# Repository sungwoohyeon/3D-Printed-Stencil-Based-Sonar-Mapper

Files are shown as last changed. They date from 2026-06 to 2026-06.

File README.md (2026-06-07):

# 3D-Printed Stencil-Based Sonar Mapper

> An **independent, in-progress reproduction** of the core idea behind **SPiDR** —
> generating a 2D cross-sectional depth map from a *single* 40 kHz speaker + a *single*
> microphone + a passive 3D-printed acoustic "stencil", by solving the linear inverse
> problem `y = H·x`.
>
> 단일 40 kHz 스피커 1개 + 마이크 1개 + 3D프린팅 패시브 "스텐실"로 2D 단면 깊이맵을
> 만드는 SPiDR 논문의 **독립 재현 프로젝트**(진행 중).

> ⚠️ **Not affiliated with the original SPiDR authors.** This repository contains only
> *our own* analysis, simulation code, bench/firmware code, and *original* 3D cap
> designs. The original paper, its figures, and the authors' published STL / MATLAB /
> datasets are **not** redistributed here — see
> [Reference material (not included)](#reference-material-not-included).

---

## What is SPiDR? (원리)

A single omnidirectional speaker emits the same signal everywhere, so it carries no
spatial information. SPiDR caps the speaker with a 3D-printed **stencil** containing
internal tubes of *different lengths*; each tube exit behaves like a secondary source
with a unique delay and attenuation. Their interference projects a **unique signal code
at every point in space**, so the scene can be recovered by solving `y = H·x`
(`H` = channel matrix, `x` = per-pixel occupancy, `y` = received mic signal).

Original paper: Yang Bai, Nakul Garg, Nirupam Roy, *SPiDR: Microstructure-Assisted
Vision for Ubiquitous Tiny Robots*, MobiSys 2022
([DOI 10.1145/3498361.3539775](https://dl.acm.org/doi/10.1145/3498361.3539775)) ·
CACM 69(3), 2026 ([DOI 10.1145/3772712](https://dl.acm.org/doi/10.1145/3772712)).
The paper is licensed CC BY-NC-SA 4.0.

## ★ Key insight of this reproduction (재현의 핵심)

The usable channel matrix **`H` must be measured empirically** — by scanning a point
reflector across a grid — rather than computed from a closed-form model. The analytic
`H` mismatches reality (time-domain round trip, near-field geometry, tube acoustics).
Our **G0** simulation demonstrates exactly this: reconstruction stays robust under small
model mismatch but collapses under large mismatch, so an empirically measured `H` is the
heart of the project.

## Repository layout

| Path | Contents |
|---|---|
| `00–07_*.md` | Korean project docs: overview, paper analysis, parts/BOM, simulation design, stencil 3D-print guide, bench + empirical-`H` guide, staged build guide, references |
| `sim/` | Time-domain forward model (`forward_model.py`), reconstruction (`reconstruct.py` — NNLS / Tikhonov / LASSO), stencil design search (`design_stencil.py`), and the **G0** model-mismatch gate (`validate_mismatch.py`) |
| `bench/` | ESP32-S3 firmware (`esp32_firmware/spidr_bench.ino`), DAQ I/O (`daq_io.py`), and the empirical-`H` scanning protocol (`measure_H.py`) |
| `models/` | Our **original** Fusion 360 build scripts and exported caps: `SPiDR_phasecap_v2` (variable path-length phase cap) and `SPiDR_stencil_parametric` (equal-length radial control cap) |

## Status

- ✅ **G0 — Simulation**: PASS. Time-domain `H`, reconstruction, and model-mismatch
  validation (inverse crime avoided).
- ⏳ **G1–G3 — Hardware**: electronics bring-up → 1D empirical-`H` → coarse 2D map.
  Pending parts assembly.

Honest expectation: 1D / coarse-2D results are realistic; paper-grade 1 cm resolution
and SSIM > 80% is a stretch goal.

## Quick start (simulation)

```bash
pip install numpy scipy        # scikit-learn optional (for LASSO)
cd sim
python design_stencil.py       # stencil optimization -> stencil_design.npz
python validate_mismatch.py    # the G0 gate
```

## Reference material (not included)

To respect copyright, the following are **not** stored in this repository. Please obtain
them from their original sources:

- **Stencil STL files** (helical; authored in *meters* — scale ×1000 for millimeters):
  [Nakul22/Spidr_Mobisys22](https://github.com/Nakul22/Spidr_Mobisys22)
- **Stencil-optimization MATLAB and `cardoid_used.mat`**:
  [Nakul22/Owlet_Mobisys21](https://github.com/Nakul22/Owlet_Mobisys21)
- **Paper text and figures**: via the DOIs above (CC BY-NC-SA 4.0).

## License

- **Our code, documentation, and original 3D designs** are released under the
  [MIT License](LICENSE) © 2026 sungwoohyeon.
- The reproduced *concept* derives from the SPiDR paper (CC BY-NC-SA 4.0); please cite
  the original authors. This project is non-commercial and unaffiliated.

## Acknowledgements

Original SPiDR and Owlet research by Yang Bai, Nakul Garg, and Nirupam Roy
(University of Maryland, iCoSMoS Lab).

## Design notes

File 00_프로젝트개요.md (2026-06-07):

> 작성일: 2026-06-04 | 프로젝트: SPiDR 독립 재현 (3D 음향 스텐실로 2D 맵 생성)
> 출처 논문: SPiDR — Microstructure-Assisted Vision for Ubiquitous Tiny Robots (UMD)
> 게재: MobiSys 2022 (DOI 10.1145/3498361.3539775) · CACM Vol.69 No.3 (March 2026, DOI 10.1145/3772712)
> 계획 리뷰: Codex gpt-5.5 (xhigh) 기술 검토 반영 (rev2)

# SPiDR 재현 — 프로젝트 개요

## 한 줄 정의

**40kHz 스피커 1개 + 마이크 1개 + 3D프린팅 패시브 "스텐실" 1개**로, 물체에 반사된 초음파를 분석해 책상 위 **2D 단면 점유맵(depth-map)**을 만드는 시스템을 직접 재현한다.

```
   [ESP32-S3]──PWM 40kHz──>[스피커]──))) 
        │                      └─[스텐실: 내부 튜브가 방향별 고유 코드 생성]
        │                              )))  ──> [물체] ──반사──┐
        └──ADC<──[프리앰프]<──[마이크]<───────────────────────┘
        │
        └──USB시리얼──> [PC: y=Hx 복원 → 2D 맵]
```

## 핵심 원리 (왜 카메라 없이 2D가 나오나)

스텐실 내부의 길이가 다른 여러 튜브가 하나의 스피커 소리를 **방향마다 다른 진폭·위상 조합(공간 코드)**으로 쪼개 내보낸다. 어떤 위치에 물체가 있으면 그 위치 고유의 코드가 마이크로 되돌아온다. 모든 위치의 코드를 미리 아는 행렬 `H`에 담아두면, 받은 신호 `y`에서 물체 위치 `x`를 역으로 푼다: **`y = H·x`**.

> **이 프로젝트의 핵심 통찰(Codex 리뷰):** `H`를 수식으로 "계산"하려 하면 실제와 안 맞는다(근거리·튜브 음향·왕복 경로). 대신 **점반사체를 격자 위로 옮기며 `H`를 직접 "측정"**하면 부정확한 모델 없이도 영상이 나온다. → **실측 H가 이 재현의 심장.**

## 성공 기준 (게이트형 단계)

| Gate | 목표 | 통과 기준 |
|---|---|---|
| **G0** 시뮬레이션 | 복원 알고리즘 검증 | 섭동 모델로 만든 데이터를 다른 H로 복원해 단일 타깃 위치 맞히기 (자기복원❌) |
| **G1** 전자 | ESP32 40kHz 송수신 | 6/10/15cm 점반사 에코를 배경차감 후 분리 검출 |
| **G2** 스텐실+1D | 스텐실 출력 + 1D 실측 H | 두 물체를 좌우로 분해 |
| **G3** coarse 2D | 실측 H로 2D 복원 | 2cm 격자 점유맵 생성 |

## 정직한 기대치

- **현실적 1차 목표:** 1D 또는 거친(2cm 격자) 2D 점유맵. 성공 확신 ~50~60%.
- **Stretch goal:** 논문 수준 1cm 격자·2cm 간격 분해·SSIM>80%. 확신 ~20~30%.
- 논문의 9.9mW·12fps·CR2032 3일은 **임베디드 저전력 최적화**라 데스크탑 재현 범위 밖(후속).

## 비용 요약 — ~$18 (+레진)

측정 장비를 **보유 ESP32-S3로 대체**($0)하여 비용 최소화. 상세는 [02_부품_구매가이드](02_부품_구매가이드.md).

| 스피커 | 마이크+프리앰프 | 드라이버 | 측정도구 | 패시브 | 합계 |
|---|---|---|---|---|---|
| ~$3 | ~$6 | ~$1 | 보유 ESP32 $0 | ~$8 | **~$18** |

## 문서 맵

| 문서 | 내용 |
|---|---|
| [01_논문분석](01_논문분석.md) | 논문 핵심 원리·수식·성능 (독립 재현 관점) |
| [02_부품_구매가이드](02_부품_구매가이드.md) | BOM + 구매 링크 + 한국 구매 메모 |
| [03_시뮬레이션_설계](03_시뮬레이션_설계.md) | 시간영역 H·복원·미스매치 검증 (`sim/`) |
| [04_스텐실_3D설계가이드](04_스텐실_3D설계가이드.md) | 공개 STL + Fusion 360 파라메트릭 설계 |
| [05_벤치_및_실측H_가이드](05_벤치_및_실측H_가이드.md) | ★코어★ 회로·실측 H·배경차감 |
| [06_구현가이드_단계별](06_구현가이드_단계별.md) | G0→G3 단계별 실행 |
| [07_참고자료](07_참고자료.md) | GitHub·논문·코드 링크 |

## 확보된 공개 자산 (검증 완료)

- `stencils/stencil_3cm.stl` (Ø28×20mm), `stencil_5cm.stl` (Ø28×40mm), `stencil_7cm.stl` (Ø50×55mm) — **실제 SPiDR 스텐실** (GitHub `Nakul22/Spidr_Mobisys22`).
  - ⚠️ **단위가 미터(m)다.** 슬라이서/Fusion에서 mm로 읽으면 28µm 먼지로 보임 → **×1000 스케일** 필수.
- `sim/ref_optimizeStencil.m` — Owlet 설계 알고리즘 원본 (해석적 회절 모델 + 랜덤서치).
- `data/cardoid_used.mat` — 실측 스피커 지향성 데이터.

## 빠른 시작

1. `02_부품_구매가이드` 보고 부품 주문 (~$18) — 동시에 G0 진행 가능
2. `sim/` 의 G0(시뮬) 실행으로 복원 원리 검증 (하드웨어 불필요)
3. `stencils/stencil_5cm.stl` ×1000 스케일 후 레진 출력
4. `06_구현가이드_단계별` 따라 G1→G3

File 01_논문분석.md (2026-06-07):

> 작성일: 2026-06-04 | 산출물① 논문 분석 (독립 재현 관점)
> 대상: SPiDR (MobiSys 2022 / CACM March 2026) · 저자 Yang Bai, Nakul Garg, Nirupam Roy (UMD iCoSMoS Lab)

# SPiDR 논문 분석

## 1. 기본 정보

| 항목 | 내용 |
|---|---|
| 제목 | SPiDR: Microstructure-Assisted Vision for Ubiquitous Tiny Robots |
| 약자 | **S**tructure-assisted **P**erception, **D**etection, and **R**anging |
| 저자 | Yang Bai, Nakul Garg, Nirupam Roy (University of Maryland) |
| 게재 | MobiSys 2022 (원본, DOI 10.1145/3498361.3539775) → CACM 69(3) 2026 재게재 (DOI 10.1145/3772712) |
| 라이선스 | CC BY-NC-SA 4.0 |
| 코드/STL | 스텐실 STL 3종만 공개 (`Nakul22/Spidr_Mobisys22`). 최적화·복원 코드 미공개 |

## 2. 해결 문제

곤충 크기(수 인치) 초소형 로봇은 **SWaP-C**(Size·Weight·Power·Cost) 제약이 극심하다. 로코모션에 전력을 쓰고 나면 센싱에 **10~30mW**만 남는다. 기존 depth 센싱은 부적합:
- **LiDAR:** 기계적 스캔 → 전력·크기 과다
- **빔포밍 소나/위상배열:** 다수 트랜스듀서 + 병렬 송수신 체인 → 연산·전력 과다

SPiDR은 **단일 스피커/마이크 + 패시브 구조물**로 이 문제를 우회한다.

## 3. 핵심 아이디어 — 구조-보조 공간 코딩

단일 무지향성 스피커는 모든 방향에 같은 신호를 보내 공간 정보를 못 만든다. SPiDR은 스피커 위에 **3D프린팅 "스텐실"**(다공성 캡)을 씌운다:
- 내부에 **길이가 다른 여러 튜브(나선 경로)**가 있고, 각 튜브 출구는 다른 방향을 향한다.
- 각 출구는 **고유한 지연·감쇠(복소 게인)**를 가진 **이차 음원**처럼 동작한다.
- 이 이차 음원들이 간섭하여, **공간의 각 지점마다 고유한 신호 패턴(코드)**을 투사한다.
- 멀티패스(다중경로)를 통신에선 잡음으로 보지만, 여기선 **의도적으로 설계**해 공간 코드로 쓴다.

> 연구 계보: **Owlet**(MobiSys'21, 마이크측 메타물질로 방향 추정 DoA) → **Sirius**(MobiSys'23, RF 자기위치) → **SPiDR**(깊이 이미징).

## 4. 측정 모델 — `y = H·x` (★시간영역 ToF★)

장면을 거리 평면 위 픽셀들로 이산화한다(20cm폭 × 10cm깊이, 1cm → N=200 픽셀).
- **`H`** : M×N 채널 행렬. 각 열 = "픽셀 i에 이상적 반사체가 있을 때 마이크가 받는 신호".
- **`x`** : 픽셀 점유 벡터(반사율). 물체 있으면 큰 값, 없으면 0.
- **`y`** : 마이크 수신 신호. `y = Hx` → `x`를 역으로 복원.

> **⚠️ 재현 시 가장 중요한 정정(Codex 리뷰):** `y`는 단일 주파수 위상값이 아니라 **시간영역 신호**다. 논문은 **10주기 톤버스트**(38–42kHz, 1kHz 간격 5개 주파수)를 쏘고 **비행시간(ToF)**으로 거리를 안다.
> - **M = (레인지게이트 내 시간 샘플 수) × (주파수 수)**. 논문 예: 5ms @ 200kHz = 1000샘플 → M≈1000.
> - 따라서 `H`의 각 열은 단일 복소수가 아니라 **샘플된 시계열(임펄스응답)**이어야 한다. CW 위상 모델만 쓰면 거리 차원(=측정의 대부분)을 잃는다.
> - 신호 경로는 **왕복**: 스피커→스텐실 출구→픽셀→반사→마이크. 진폭은 `1/(r_송신·r_수신)`(단일 `1/d` 아님).

## 5. 4대 핵심 기법

### 5.1 멀티패스 합성 (스텐실 최적화)
임의 스텐실은 충분한 코드 다양성을 못 준다. **각 픽셀에서의 신호 상관도를 낮추도록** 튜브 길이를 최적화한다. 논문은 "홀로그래피의 Weighted Gerchberg-Saxton(GS) 알고리즘과 유사"라고 기술. (실제 공개된 Owlet 코드는 **랜덤서치** — 6절 참조.)

### 5.2 주파수 스태킹
튜브 길이가 같아도 **주파수가 바뀌면 위상 코드가 달라진다.** 38–42kHz의 5개 주파수 측정을 결합(스태킹)해 H의 행 수(측정 수)를 늘려 복원 품질을 높인다.

### 5.3 모션 스태킹
로봇 이동 중 같은 장면의 여러 스냅샷을 **mean/median 스태킹**으로 결합(O(n)/O(log n))해 잡음·허상 억제. 최대 170fps 가능.

### 5.4 Fractional Scene Computing (저전력 복원)
전체 H 역변환 대신: ① 인접 상관 픽셀을 **메타픽셀**로 묶어 축소 H로 거친 복원 → ② 물체 있는 영역만 **반복적 고해상도 정밀화** → ③ 역행렬을 **사전계산·프리페치**. Raspberry Pi 4에서 최적화 조합 시 **1380× 에너지 절감**.
> 이 기법은 **임베디드 저전력**용. 데스크탑 PC 재현에선 불필요(표준 역변환으로 충분).

## 6. 포워드 모델 수식

논문 eq.(1) — 픽셀 m에서의 음압:

```
p_m = i·(ρ c k S / 2π) · Σ_{n=1..N} a_n · e^(i2πft) · e^(−i k d_mn) / d_mn
```
- `a_n, ` = 이차음원 n의 진폭·시간지연, `f` = 주파수, `k` = 2πf/c (파수)
- `d_mn` = 음원 n→픽셀 m 거리, `ρ, c` = 공기 밀도·음속, `S` = 반사면적(단위상수)
- Weighted GS(홀로그램, Di Leonardo 2007)와 동형.

**Owlet 공개 코드(`ref_optimizeStencil.m`)의 실제 모델** — 마이크측이지만 물리 동일:
- 실린더(내경 17.5 / 외경 30 / 높이 60 mm), 홀 20개를 (높이, 각도)로 배치
- 홀 기여: `(D/(jλr²))·exp(−j·2π/λ·(r + added_distance))·cardioid(angle)`
  - `r = √(D² + 홀높이²)`, `added_distance` = 외벽을 감아 도는 추가 경로(= 위상 코드 원천)
- 최적화 = **랜덤 홀패턴 N개 생성 → 각도별 주파수 시그니처의 다양성(인접 각도 차이 합) 최대 → 최선 선택.** (gradient WGS 아님)
- 측정 지향성(`cardoid_used.mat`)으로 스피커/마이크 방사패턴 보정.

→ 재현 시 이 코드를 **스피커측(송신)으로 변형**하고 `added_distance`를 **제어 가능한 튜브 길이 `l_n`**으로 바꾸면 된다.

## 7. 성능 수치 (논문)

| 지표 | 값 |
|---|-----|
| 전력 | 9.9mW (= 0.83mJ/frame) |
| 분해: 트랜스듀서 0.035 + ADC 0.024 + 마이크 0.245 + 연산 0.526 = **0.83mJ** |
| 프레임레이트 | 12 fps (최대 170fps) |
| 장면 | 20cm폭 × 6~15cm깊이, 1cm 해상도(200픽셀) |
| 정확도 | SSIM >80%, RMSE <0.5cm (sparsity 60%+) |
| 최소 분해 | 2cm 간격 두 물체 구분 |
| 배터리 | CR2032 코인셀 3일 연속 |
| 비교 | LiDAR 대비 400× 저전력, 64-마이크 어레이 대비 19× |
| 강건성 | 환경소음 무영향(40kHz 대역), 재료(카드보드/나무/레진) 무관 |

## 8. 재현 가능성 분석 (무엇이 쉽고 무엇이 어려운가)

| 요소 | 상태 | 재현 난이도 |
|---|---|---|
| 스텐실 형상 | **STL 공개** (3/5/7cm) | 쉬움 — 출력만 |
| 설계 알고리즘 | Owlet 코드 공개(랜덤서치) | 중 — 송신측 변형 |
| 포워드 모델 | eq.1 공개, 단 단순화됨 | 중 — 시간영역·왕복 확장 필요 |
| **채널행렬 H** | **미공개** | **어려움 — 실측 필요(이 재현의 핵심 작업)** |
| 복원 알고리즘 | 미공개, 원리 기술 | 중 — 표준 역문제(LASSO/LSQR) |
| 측정 데이터셋 | 미공개 | — 자체 수집 |

## 9. 한계 (논문 명시 + 재현 관점)

- 감지 범위 6~15cm로 제한(멀수록 반사 약화 → 블러). **근거리(near-field)** 영역(Fraunhofer 거리 ≈0.58m ≫ 15cm)이라 원거리 근사 불가.
- 희소 장면(sparsity 60%+) 특화, 밀집 환경 성능 저하.
- 2D 단면만(완전 3D는 미래 과제).
- 40kHz 한계로 해상도 제약.

## 주의사항 · 불확실성

- **시간영역 측정모델**을 놓치면 거리 정보를 잃는다(4절). 재현 코드는 톤버스트·ToF·게이팅을 반영해야 한다.
- **고Q 피에조 링다운**(~0.24ms)이 6cm 왕복(0.35ms)과 겹쳐 근거리 에코를 가릴 수 있다 → Tx/Rx 분리·배경차감 필수([05](05_벤치_및_실측H_가이드.md)).
- 스텐실 STL은 **미터 단위** → 출력 시 ×1000.
- 논문 SSIM>80%는 **실측 H + 캘리브레이션**이 전제. 데스크탑 1차 재현의 정직한 목표는 1D/거친 2D.

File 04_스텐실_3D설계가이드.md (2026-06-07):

> 작성일: 2026-06-04 | 산출물③ 스텐실 3D 모델링 (Codex gpt-5.5 리뷰 반영, 출력 준비 완료)

# 스텐실 3D 설계 가이드 — 내일 출력용

## ★결론: 내일 무엇을 출력하나★

**1순위 (반드시): `stencils/print_ready/stencil_5cm_mm.stl`** — 실제 SPiDR 스텐실(검증된 가변길이 나선 튜브). Ø28×40mm, **이미 mm 단위라 스케일 불필요**. Codex 권고: "가장 안전한 음향적 선택."

**2순위 (우리 설계, 같이 출력 권장): `models/SPiDR_phasecap_v2.stl`** — 가변 경로길이 위상캡(아래 설명). Ø30×40mm, mm 단위.

**참고용(선택): `models/SPiDR_stencil_parametric.stl`** — 동일길이 라디얼 홀 캡. **대조군(control)으로만.** Codex: 위상 다양성 부족해 단독 사용 비권장.

> 베드 여유 있으면 **5cm_mm + phasecap_v2 같이** 출력 → 둘 비교. 시간 없으면 5cm_mm 하나만.

## 왜 v1(동일길이 라디얼 캡)은 부족한가 (Codex)

내 첫 설계는 20개 홀이 모두 같은 길이(벽 5.5mm)라 **위상이 거의 같은(co-phased)** 점음원 배열 → 다양성이 위치뿐. 40kHz·Ø28mm 개구의 각분해능 ≈ λ/D = 8.6/28 ≈ **18°** → 15cm에서 가로 ~5cm 분해. 20cm 폭을 ~10칸으로 나누기엔 부족. **가변 경로길이가 필수.**

## 왜 360° 원통형인가 (방향 — 검증 완료)

스텐실은 **완전한 360° 원통**이 맞다. (공개 STL 메시 분석: 튜브가 12/12 방위 섹터 균일 분포 / Owlet 코드: 홀 각도 0~360° / Codex 확인.)
- 스텐실은 **지향성 프로젝터가 아니라 근거리 간섭·회절 "코더"** 다. 각 구멍=지연·감쇠 가진 2차 음원, 작은 구멍은 소리를 넓게 회절 → **옆·뒤 구멍도 앞 장면에 기여**. 핵심은 "앞으로 모으기"가 아니라 **구멍 위치·경로길이 다양성**. 근거리(Fraunhofer~58cm≫15cm)라 옆·뒤도 비슷한 거리.
- **Forward-bias(앞쪽 집중)는 비권장:** 앞 SNR은 조금↑ 가능하나, 위치 다양성↓ → H 열 상관↑(조건수 악화) → 복원 품질↓ 가능성.
- **★마운트 방향(논문 Fig.2 확인)★:** **구멍(소리 나오는 면)이 목표를 향한다.** 스피커는 반대쪽 캐비티에 꽂혀 **캡 안으로** 발사(목표 직접 안 봄 — 캡이 코딩), 마이크는 캡 옆. 순서: 스피커→캡(코딩)→구멍에서 코드음→반사→마이크. 논문 헬리컬(`stencil_5cm_mm`)은 구멍이 **끝면**이라 그 면을 목표로 / 우리 v2는 구멍이 **옆면**이라 옆을 목표로(배치 달라 비추천). **H 측정은 이 배치 그대로** ([05](05_벤치_및_실측H_가이드.md)).

## 세 가지 옵션

| 파일 | 설계 | 치수 | 위상 다양성 | 용도 |
|---|---|---|---|---|
| `print_ready/stencil_5cm_mm.stl` | 실제 SPiDR 나선 튜브 | Ø28×40mm | ★★★ (검증됨) | **1순위 출력** |
| `models/SPiDR_phasecap_v2.stl` | 중앙기둥+높이별 배출홀 | Ø30×40mm | ★★ (경로 12~35mm) | **우리 설계, 2순위** |
| `models/SPiDR_stencil_parametric.stl` | 동일길이 라디얼 홀 | Ø28×20mm | ★ (위치만) | 대조군 |

## v2 위상캡 설계 (우리 설계, Fusion 빌드·검증 완료)

**원리:** 소리가 바닥 트랜스듀서 → **중앙 Ø10mm 기둥**으로 상승 → 서로 **다른 높이의 16개 라디얼 홀**로 배출. 각 홀까지의 상승 거리가 다르므로 **채널마다 경로길이가 다름**(=Owlet의 위상 코딩 메커니즘).
- Ø30 OD × 40mm. 바닥 Ø16.7 캐비티(16mm 트랜스듀서, 깊이 12mm) + 시팅 레지. 중앙 Ø10 기둥(12→38mm). 측벽 16홀 Ø2.3, 높이 14~37mm.
- **검증(Fusion 실측):** 바디 1개, vol 22.81cm³, 경로길이 **12~35mm(스프레드 23mm ≈ 2.7λ)** → 실질적 위상 다양성. 원통면 20.
- 빌드 스크립트: `models/build_phasecap_v2_fusion.py` (파라미터 수정·재생성용).

## 공개 STL (1순위) 준비 상태

`stencils/print_ready/`에 **미터→mm 변환 완료**:
| 파일 | 치수 |
|---|---|
| `stencil_3cm_mm.stl` | Ø28×20mm |
| `stencil_5cm_mm.stl` | **Ø28×40mm ← 권장** |
| `stencil_7cm_mm.stl` | Ø50×55mm |
> 원본 `stencils/stencil_*.stl`은 미터 단위(먼지로 보임). **반드시 `print_ready/` 의 _mm 버전 사용.**

## ★레진 MSLA 출력 준비 (Codex 권고 — 필독)★

**방향(orientation):**
- 캡 축을 **30~45° 기울여** 배치.
- **트랜스듀서 캐비티(개방부)는 아래(베드/배트 쪽)로** 향하게 → 밀폐 진공(suction) 방지.
- 모든 채널·캐비티가 양끝 개방이면 **드레인 홀 불필요**. (공개 STL 나선 튜브가 막힌 곳 있으면 출력 후 IPA 주사기로 관통.)

**서포트:**
- **외부에만** 서포트. 캐비티(Ø16.7)·기둥·홀 **내부엔 절대 금지**.
- 출구 림 근처는 가벼운 서포트 가능.

**홀 막힘 방지:**
- Ø2.3mm로 모델링됨(목표 Ø2mm + 여유). 35~50µm MSLA에서 출력 OK.
- **출력 직후·경화 전** 모든 채널에 IPA 주사 → 에어블로어로 관통 확인. **경화 후엔 못 뚫음.**

**트랜스듀서 장착:**
- 16mm 트랜스듀서 ↔ Ø16.7 캐비티 = **슬립 핏**(억지 끼움 금지, 레진 깨짐). 헐거우면 정상.
- 삽입부 0.5mm 모따기(없으면 손으로 살짝 다듬기). v2엔 시팅 레지 있음.
- **둘레를 RTV 실리콘/왁스로 기밀 밀봉** — 누설이 성능 최대의 적.

**★출력 전 MUST-FIX 체크리스트:**
- [ ] 공개 STL은 `print_ready/`의 **_mm 버전** 사용(원본 미터 금지)
- [ ] 슬라이서에서 치수 확인: 5cm = ~Ø28×40mm
- [ ] 음향 경로 **내부 서포트 0개**
- [ ] 출력 후 **모든 홀 관통**(IPA+에어) — 경화 전
- [ ] 트랜스듀서 **기밀 밀봉**(실리콘)
- [ ] 레진 SLA만(FDM 금지), 405nm 2~4분 후경화

## 다음
출력한 스텐실 → [05_벤치_및_실측H_가이드](05_벤치_및_실측H_가이드.md) H 측정 → [06](06_구현가이드_단계별.md) G2/G3.

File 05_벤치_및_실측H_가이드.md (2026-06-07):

> 작성일: 2026-06-04 | ★재현의 심장★ 벤치 회로 + 실측 채널행렬 H
> 코드: `bench/esp32_firmware/spidr_bench.ino`(제공), `bench/daq_io.py`, `bench/measure_H.py`

# 벤치 + 실측 H 가이드

복원의 성패는 **H를 얼마나 정확히 측정하느냐**에 달렸다. 수식 H는 시작점일 뿐, 사용 가능한 H는 측정해야 한다(G0가 증명).

## 1. 회로

```
ESP32-S3 GPIO4 ──> [SN74LVC2G04 버퍼] ──> 40kHz 스피커(송신)
                                              )))  스텐실
스피커  ──흡음 배플──  마이크   (직접 누설 차단!)
40kHz 마이크 ──> [OPA344 ~40dB + 밴드패스 35~45kHz] ──+1.65V 바이어스──> ESP32-S3 ADC(GPIO?)
ESP32-S3 ──USB──> PC
```
- **송신:** ESP32 PWM(40kHz)은 약하므로 SN74LVC2G04로 버퍼(또는 트랜지스터). 5V 구동이면 출력↑.
- **수신 바이어스:** ADC는 0~3.3V만 → 프리앰프 출력에 +1.65V DC 더해 중앙 정렬(저항분압 + 1µF 결합).
- **밴드패스:** 35~45kHz만 통과(가청 잡음·DC 제거). 간단히는 RC 1차 ×2.
- **★배플★:** 스피커와 마이크 사이 흡음폼/칸막이. **직접 누설(crosstalk)이 근거리 최대의 적.**
- **★마운트 방향(논문 Fig.2 확인):** **구멍(소리 나오는 면)이 목표를 향한다.** 스피커는 반대쪽 **캐비티에 꽂혀 캡 안으로** 발사(목표를 직접 보지 않음, 캡이 코딩). 마이크는 캡 옆에서 반사음 청취. 순서: 스피커→캡(코딩)→구멍에서 코드음→목표 반사→마이크.
  - 논문 헬리컬 스텐실(`stencil_5cm_mm`): 구멍이 **끝면**에 있음 → 그 면을 목표로, 스피커는 뒤 캐비티.
  - 우리 v2(옆구멍): 구멍이 **옆면** → 옆면을 목표로 (배치가 달라 비추천).
  - **이 배치(구멍 면·스피커·마이크 위치)를 고정한 채 H 측정**, 이후 측정도 같은 배치 유지(바뀌면 H 무효). 왜 360°인지는 [04 §왜 360°](04_스텐실_3D설계가이드.md).

## 2. 펌웨어 업로드 (사용자는 업로드만)

1. Arduino IDE → 보드 매니저에서 **esp32 core 3.x** 설치(`analogContinuous` 필요).
2. 보드 = "ESP32S3 Dev Module", 포트 선택.
3. `bench/esp32_firmware/spidr_bench.ino` 열기 → 상단 상수 확인:
   - `TX_PIN`, `RX_ADC_CH`(보드 핀맵 확인), `SAMPLE_HZ=200000`, `WIN_SAMPLES=240`.
4. 업로드 → 시리얼 모니터(2,000,000 baud)에 `# SPiDR bench ready` 뜨면 OK.

## 3. G1 — 전자 검증 (스텐실 없이)

1. **Q/링다운 측정:** 버스트 1발 송출 → 마이크 파형 확인. 감쇠시간 ≈ Q/(π·40k). 6cm 왕복(0.35ms)보다 길면 근거리 가림 → 배플·게이팅 강화.
2. **직접 누설:** 물체 없이 캡처 → 송신 직후 큰 누설이 보임. 이게 **배경(blank)**.
3. **단일 반사:** 6/10/15cm에 판 1개 → 배경 빼면 에코가 시간축 다른 위치에 보여야 함(ToF). 안 보이면 게인·배플·게이트 조정.
   - ⚠️ ESP32 ADC가 200kHz 연속을 못 버티면(드롭/지터) → `SAMPLE_HZ` 낮추거나 라즈베리파이 Pico 폴백([02](02_부품_구매가이드.md)).

## 4. G2/G3 — 실측 H (코어)

스텐실 장착 후:

```bash
cd bench
python measure_H.py --sim                 # (먼저) 하드웨어 없이 파이프라인 점검 → H_measured.npz
python measure_H.py --port COM5 --pitch 2 --depth 10   # 실제 측정 (포트는 장치관리자 확인)
```

**프로토콜(measure_H.py가 안내):**
1. **배경:** 물체 다 치우고 측정 → blank.
2. **스캔:** 작은 점반사체(Ø6mm 금속구/볼트)를 픽셀 격자 각 위치로 이동하며 측정.
   - 1D 먼저: 가로 −10~+10cm, 2cm 간격(11점), 깊이 10cm 고정. **손+자+3D프린트 지그로 충분**(모터 불필요).
3. 각 측정 = (blank 차감) + 동기 평균(기본 32회, SNR↑) → H의 그 열.
4. 완료 → `H_measured.npz`. 출력되는 **열 결맞음·조건수**로 코드 품질 확인(낮을수록 좋음).

**음속/온도:** `c = 331.3 + 0.606·T(°C)`. 1°C 변동도 수십° 위상 이동 → 측정 중 온도 기록, 필요시 보정.

## 5. 실제 장면 복원 (G3)

```python
import numpy as np, sys; sys.path.insert(0,'../sim')
from reconstruct import reconstruct_nnls, detect_recall
d = np.load('H_measured.npz'); H = d['H']
# 실제 장면(물체 배치) 1회 캡처 → y (blank 차감, to_column)
# x_hat = reconstruct_nnls(H, y)  → 점유맵
```
- 시작은 단일 물체 위치 맞히기 → 두 물체 2cm 분해 → 거친 2D(2cm 격자, depth 여러 층 측정).
- **SNR 부족하면 평균 횟수↑**(논문 12fps는 임베디드 최적화 결과 — 벤치 초기엔 느려도 정상).

## 6. 트러블슈팅

| 증상 | 원인/조치 |
|---|---|
| 에코 안 보임 | 누설·링다운이 가림 → 배플 강화, 레인지게이트 시작 늦춤, 게인↑ |
| 복원 잡음 많음 | H 결맞음 높음 → 스텐실 재설계(홀 다양성↑) 또는 주파수/평균↑ |
| 위치 어긋남 | 마이크/픽셀 좌표 오차(수mm=큰 위상) → 좌표 정밀 재측정 |
| ADC 드롭 | 200kHz 연속 실패 → SAMPLE_HZ↓ 또는 Pico |
| 클리핑 | 프리앰프 게인↓ 또는 바이어스 재조정 |

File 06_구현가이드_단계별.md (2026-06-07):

> 작성일: 2026-06-04 | 산출물④ 단계별 구현 가이드 (게이트형)

# 단계별 구현 가이드

각 게이트는 **통과 기준**을 만족해야 다음으로. 한 번에 다 하지 말 것.

## 진행 현황 (2026-06-04)

| 단계 | 상태 |
|---|---|
| 공개 STL·Owlet 코드 확보 | ✅ `stencils/`, `sim/ref_optimizeStencil.m`, `data/cardoid_used.mat` |
| **G0 시뮬레이션** | ✅ **PASS** (단일·이중 타깃, 모델 불일치 검증) |
| 스텐실 파라메트릭 모델 | ✅ Fusion 빌드·검증·익스포트 (`models/`) |
| 문서 ①~④ | ✅ 작성 완료 |
| G1~G3 (하드웨어) | ⏳ 부품 구매 후 |

---

## G0 — 시뮬레이션 ✅ (완료)

**목표:** 하드웨어 전, 복원 알고리즘·접근법을 모델 불일치 하에서 검증.

```bash
cd sim
python design_stencil.py        # 스텐실 최적화 → stencil_design.npz
python validate_mismatch.py     # G0 게이트
```
**통과 기준:** 작은 불일치(튜브 보정)에서 타깃검출 recall ≥80%. → **달성**(단일·이중 100%).
**핵심 교훈:** 큰 불일치에서 붕괴(47~53%) → ∴ 실측 H 필수. 자세히 [03](03_시뮬레이션_설계.md).

---

## G1 — 전자 검증 ⏳ (부품 후)

**목표:** ESP32로 40kHz 송수신, 누설·링다운·단일반사 확인.

1. 회로 조립([05 §1](05_벤치_및_실측H_가이드.md)) — 스피커+버퍼, 마이크+프리앰프+바이어스, **배플**.
2. `spidr_bench.ino` 업로드([05 §2](05_벤치_및_실측H_가이드.md)).
3. 빈 상태 캡처(배경) + 6/10/15cm 판 반사 캡처.

**통과 기준:** 배경 차감 후 6·10·15cm 에코가 **시간축 다른 위치**에 분리되어 보임.
**막히면:** 200kHz ADC 검증 실패 → `SAMPLE_HZ`↓ 또는 Pico. 에코 가림 → 배플·게이트.

---

## G2 — 스텐실 + 1D 실측 H ⏳

**목표:** 스텐실 장착 후, 점반사체 1D 스캔으로 H 측정 → 위치 분해.

1. 스텐실 출력([04](04_스텐실_3D설계가이드.md)) — `stencil_5cm.stl`(×1000!) 또는 `models/SPiDR_stencil_parametric.stl`.
2. 스피커에 스텐실 씌우고 캐비티 밀봉(누설 방지).
3. 1D 실측 H:
   ```bash
   cd bench
   python measure_H.py --port COM5 --pitch 2 --depth 10   # 11점, 손 지그
   ```
4. 단일 타깃 위치 맞히기 → **두 물체 2cm 분해**.

**통과 기준:** 측정 H로 두 반사체를 좌우 분해. H 결맞음·조건수가 합리적(낮음).

---

## G3 — 거친 2D ⏳

**목표:** 실측 H로 2cm 격자 2D 점유맵.

1. 깊이 여러 층(예: 6·8·10·12cm) 각각 1D H 측정 → 2D H 결합. (또는 2D 격자 직접 스캔)
2. 실제 장면(물체 1~3개) 캡처 → `reconstruct_nnls(H, y)` → 점유맵 시각화.
3. 점진적으로 1cm·2cm갭 도전(stretch).

**통과 기준:** 단순 장면의 2D 점유맵 생성. (논문급 1cm/SSIM>80%는 stretch — [00 기대치](00_프로젝트개요.md))

---

## 의존성 설치

```bash
pip install numpy scipy            # 필수 (scipy 설치 완료)
pip install scikit-learn pyserial  # 선택(LASSO) / 하드웨어(시리얼)
```

## 자주 막히는 곳 (요약)

- **STL 단위 미터** → ×1000 ([04](04_스텐실_3D설계가이드.md)).
- **직접 누설·링다운** → 배플·Tx/Rx 분리·배경차감 ([05](05_벤치_및_실측H_가이드.md)).
- **ESP32 ADC 200kHz** → 미검증, G1에서 확인, 안 되면 Pico.
- **인버스 크라임** → 시뮬 자기복원에 속지 말 것, 실측 H로 검증.
- **수식 H만으로 부족** → H를 측정하는 게 본질.

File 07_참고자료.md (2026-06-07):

> 작성일: 2026-06-04 | 산출물 보조: 참고자료·링크 모음

# 참고자료

## 논문 (원본)

- **SPiDR (MobiSys 2022, 원본):** Bai, Garg, Roy. *Ultra-low-power acoustic spatial sensing.* DOI [10.1145/3498361.3539775](https://dl.acm.org/doi/10.1145/3498361.3539775) · [PDF (UMD)](https://www.cs.umd.edu/~nakul/assets/papers/spidr_mobisys2022_nakul.pdf)
- **SPiDR (CACM 2026, 재게재):** Communications of the ACM 69(3). DOI [10.1145/3772712](https://dl.acm.org/doi/10.1145/3772712) · [CACM 페이지](https://cacm.acm.org/research-highlights/spidr-microstructure-assisted-vision-for-ubiquitous-tiny-robots/) · [Technical Perspective](https://cacm.acm.org/research-highlights/technical-perspective-spidr-helping-miniature-robots-see-sound/)
- **Owlet (선행, MobiSys'21):** Garg, Bai, Roy. *Enabling spatial information in ubiquitous acoustic devices.* — 마이크측 메타물질 DoA
- **Sirius (MobiSys'23):** Garg, Roy. *Self-localization for resource-constrained IoT.* — RF 버전
- iCoSMoS Lab (UMD): https://icosmos.cs.umd.edu/ · Nakul Garg: https://nakulg.com/

## 공개 코드/STL (이 프로젝트가 사용)

| 저장소 | 핵심 파일 | 받은 위치 |
|---|---|---|
| [Nakul22/Spidr_Mobisys22](https://github.com/Nakul22/Spidr_Mobisys22) | `stencils/stencil_3cm·5cm·7cm.stl` (미터 단위) | `stencils/` |
| [Nakul22/Owlet_Mobisys21](https://github.com/Nakul22/Owlet_Mobisys21) | `optimizeStencil.m`, `cardoid_used.mat`, STL 5종 | `sim/ref_optimizeStencil.m`, `data/cardoid_used.mat` |
| [Nakul22/Sirius](https://github.com/Nakul22/Sirius) | RF(비관련) | — |

## 알고리즘 참조 (스텐실 설계·복원)

- **Weighted Gerchberg-Saxton:** Di Leonardo et al., *Computer generation of optimal holograms for optical trap arrays*, Optics Express 15(4), 2007. [opg.optica.org](https://opg.optica.org/oe/fulltext.cfm?uri=oe-15-4-1913)
  - Python WGS 구현: [csi-dcsc/compressive-sensing-Gerchberg-Saxton](https://github.com/csi-dcsc/compressive-sensing-Gerchberg-Saxton) · [mmazzanti/SLM_phase_pattern](https://github.com/mmazzanti/SLM_phase_pattern)
- **음향 홀로그램 자동미분 최적화(WGS 대안):** [DigitalNatureGroup/Diff_PAT](https://github.com/DigitalNatureGroup/Diff_PAT) (JAX), Scientific Reports 2021
- **음향 전파 시뮬(미스매치 검증용):** [k-wave-python](https://github.com/waltsims/k-wave-python) · [pyRayleighCuda](https://github.com/vlchaplin/pyRayleighCuda)
- **복원(역문제):** scikit-learn [Lasso](https://scikit-learn.org/stable/modules/generated/sklearn.linear_model.Lasso.html), scipy `lsqr`/`lstsq`

## 후속/관련 연구

- 적응형 메타표면 음향 이미징: Fu et al., MobiSys 2024. DOI [10.1145/3643832.3661863](https://dl.acm.org/doi/10.1145/3643832.3661863)
- 음향 메타표면 센싱/통신: Zhang et al., NSDI 2023

## 하드웨어 데이터시트

- Murata [MA40S4S(송신)](https://www.digikey.com/en/products/detail/murata-electronics/MA40S4S/4358147) / [MA40S4R(수신)](https://www.digikey.com/en/products/detail/murata-electronics/MA40S4R/4358146)
- [Knowles SPH0641LU4H-1](https://www.digikey.com/en/products/detail/knowles/SPH0641LU4H-1/5332438) (초음파 MEMS, PDM, 폴백용)
- [TI OPA344](https://www.ti.com/product/OPA344) · [SN74LVC2G04](https://www.digikey.com/en/products/detail/texas-instruments/SN74LVC2G04DBVR/484834)
- ESP32-S3 ADC 연속모드: Espressif esp-idf `adc_continuous` 문서

## 사용자 기존 연관 문서

- `논문/CatPrey_논문기획_v3_hybrid/B_SPiDR_논문분석_및_적용방안.md` (CatPrey 적용 관점 분석)
- `논문/CatPrey_논문기획_v3_hybrid/C_SPiDR_재현_구매리스트.md` (초기 구매 검토, 본 프로젝트가 갱신)
- `Fusion360_MCP_모델링_핸드오프.md` (Fusion MCP 모델링 팁)

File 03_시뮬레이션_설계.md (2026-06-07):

> 작성일: 2026-06-04 | 시뮬레이션(보조 트랙) 설계 + G0 결과
> 코드: `sim/forward_model.py`, `reconstruct.py`, `design_stencil.py`, `validate_mismatch.py`
> 환경: Python 3.14 + numpy + scipy(설치됨 1.17). sklearn은 선택.

# 시뮬레이션 설계 (G0)

## 목적과 위치

시뮬레이션은 **이 재현의 본체가 아니다**(본체는 실측 H — [05](05_벤치_및_실측H_가이드.md)). 시뮬의 역할:
1. **복원 알고리즘·접근법 검증** (하드웨어 전, 무위험)
2. **스텐실 설계**(튜브 길이) 산출 → 3D 모델 파라미터 ([04](04_스텐실_3D설계가이드.md))
3. **"모델만으로는 부족함"을 정량 증명** → 실측 H 필요성의 근거

## 핵심 설계 결정 (Codex 리뷰 반영)

| 항목 | 잘못된 단순화 | 채택한 설계 |
|---|---|---|
| H 종류 | 단일주파수 위상 H | **시간영역 시계열 H** (톤버스트·ToF) |
| 신호 경로 | 스텐실→픽셀 (한쪽) | **왕복** 스텐실→픽셀→마이크, 진폭 1/(r_np·r_pm) |
| 측정 차원 M | 5주파수만 | (게이트 시간샘플 240) × (5주파수) = **1200** |
| 검증 | 같은 H 자기복원 | **모델 불일치**(섭동 물리)로만 |
| 거리 가정 | 원거리 | **근거리 구면 전파** + 마이크 좌표 |

## 모듈 구조

- **`forward_model.py`** — `Config`(음속·fs·주파수·스텐실 기하·레인지게이트), `tone_burst`(Hann 톤버스트), `make_stencil`(튜브 출구·길이), `scene_grid`(픽셀 격자), `received_signal`(픽셀 1개의 왕복 수신 시계열, 튜브에 벡터화), `build_H`(M×N).
- **`reconstruct.py`** — `reconstruct_nnls`(비음 최소제곱, 기본), `reconstruct_tikhonov`(LSQR), `reconstruct_lasso`(sklearn). 열 정규화로 조건수 개선. 평가: `detect_recall`(상위 k 피크가 참 타깃 잡은 비율), `image_corr`.
- **`design_stencil.py`** — Owlet식 랜덤서치로 튜브 위치·길이를 최적화(열 결맞음 최소화). `stencil_design.npz` 저장 → 3D 모델이 사용.
- **`validate_mismatch.py`** — G0 본체. 섭동 물리로 데이터 생성 → 공칭 H로 복원 → 불일치 수준별 정확도 스윕.

## 실행

```bash
cd sim
python forward_model.py        # H 형상·결맞음 확인
python design_stencil.py       # 스텐실 최적화 → stencil_design.npz
python validate_mismatch.py    # G0 게이트
```

## G0 결과 (실측 출력)

스텐실 최적화: 최대 결맞음 0.74(무작위) → **0.54(최적)**, 조건수 12.8. 튜브 20개, H=(1200, 11), 2cm 픽셀, SNR 30dB.

**모델 불일치 스윕 — 단일/이중 타깃 모두:**

| 불일치 수준 | 타깃검출 recall (단일) | (이중 2cm) |
|---|:---:|:---:|
| 잡음만 | 100% | 100% |
| 작음(보정됨, ~10°) | **100%** | **100%** |
| 중간(~30°) | 90% | 88% |
| 큼(미보정, 180°) | 47% | 53% |
| 인버스크라임(참고) | 100% | 100% (무의미) |

**→ G0 게이트 PASS.** 해석:
- 튜브 전달을 잘 보정한(작은 불일치) 경우, 복원기가 **2cm 간격 두 물체까지 100% 분해** → 알고리즘·접근법 타당.
- 불일치가 커지면(튜브 음향 미보정) **정확도 붕괴(47~53%)** → **수식 H만으로는 안 되고 실측 H가 필수**임을 수치로 증명.
- 인버스크라임(같은 H 자기복원)은 항상 100% → 이것만 보면 속는다(그래서 불일치 검증을 한 것).

## 한계·다음

- 1D(가로) 검증 완료. 2D(가로×깊이) 확장은 `scene_grid(x, z)`에 z 다값 주면 됨.
- 튜브 출구를 무지향성으로 둠(지향성은 섭동으로만). 실제 directivity는 `cardoid_used.mat`처럼 측정·반영 가능.
- 풀웨이브 검증(k-wave-python)으로 섭동 모델을 더 사실적으로 교체 가능(선택).

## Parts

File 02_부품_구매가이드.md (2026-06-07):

> 작성일: 2026-06-04 | 산출물② 부품 구매 가이드 (초저비용·ESP32-S3 경로)
> 전제: 레진 3D프린터 보유 / ESP32-S3 보유(CatPrey 로봇) → 측정장비 비용 $0

# 부품 구매 가이드 — 총 ~$18

## 0. 왜 이렇게 싼가 / 측정 장비 개념

센서 자체(스피커+마이크+스텐실)는 ~$10다. 유일한 진짜 비용은 **40kHz를 받을 측정 장비**:
- 40kHz는 사람 귀·일반 마이크·PC 사운드카드(최대 48kHz)가 **못 잡는다**. Nyquist상 **>80kHz 샘플링**이 필요.
- 보통 ADALM2000(~$287) 같은 실험실 장비를 쓰지만, **보유한 ESP32-S3가 같은 일을 $0에** 한다:
  - **송신:** LEDC PWM으로 40kHz 구형파 출력 (피에조가 협대역 필터링해 사인파화 → DAC 불필요)
  - **수신:** ADC 연속(DMA) 모드로 마이크 신호 샘플링 → USB 시리얼로 PC 전송
- **"펌웨어"(ESP32에 올리는 프로그램)는 이 저장소 `bench/esp32_firmware/`에 제공된다.** 사용자는 Arduino IDE로 업로드만.

## 1. BOM (Bill of Materials)

| # | 부품 | 권장 모델 | 수량 | 가격 | 구매 링크 |
|---|---|---|---|---|---|
| 1 | 40kHz 스피커(송신) | Murata MA40S4S 또는 TCT40-16T | 1~2 | ~$3 | [DigiKey MA40S4S](https://www.digikey.com/en/products/detail/murata-electronics/MA40S4S/4358147) · [AliExpress 40kHz pair](https://www.aliexpress.com/w/wholesale-40khz-ultrasonic-transducer.html) · 디바이스마트/엘레파츠 "초음파 트랜스듀서 40kHz" |
| 2 | 40kHz 마이크(수신) | Murata MA40S4R (피에조 수신) | 1~2 | ~$3 | [DigiKey MA40S4R](https://www.digikey.com/en/products/detail/murata-electronics/MA40S4R/4358146) · TCT40-16**R** 페어에 포함 |
| 3 | 프리앰프 IC | OPA344 (또는 MCP6002/LM358) | 1 | ~$2 | [TI OPA344](https://www.ti.com/product/OPA344) · 디바이스마트 "OPA344" / "MCP6002" |
| 4 | 송신 드라이버 | SN74LVC2G04 (또는 2N2222 트랜지스터) | 1 | ~$1 | [DigiKey SN74LVC2G04](https://www.digikey.com/en/products/detail/texas-instruments/SN74LVC2G04DBVR/484834) |
| 5 | **측정 도구** | **보유 ESP32-S3** | 1 | **$0** | 보유 (CatPrey) |
| 6 | 패시브 | 브레드보드, 점퍼, 0.1µF·1µF 캐패시터, 1k/10k/100k 저항 | 1세트 | ~$6 | 디바이스마트/엘레파츠/알리 |
| 7 | 흡음폼/배플 | 멜라민 스펀지·펠트 (Tx/Rx 누설 차단) | 소량 | ~$2 | 다이소/문구점 가능 |
| 8 | 온도센서(선택) | DS18B20 등 (음속 보정) | 1 | ~$2 | 보유 가능 |
| 9 | 405nm 레진 | 표준 그레이/화이트 1kg | — | ~$0–18 | 보유 프린터용 (이미 보유 가능) |
| | | | | **합계 ~$18** | |

### TCT40-16 페어가 가장 저렴 (한국)
송신 `T` + 수신 `R` 한 쌍이 알리/디바이스마트에서 ~$1~3. 16mm 직경, 40kHz±1kHz. 1·2번을 이걸로 한 번에 해결. 여분 위해 10T+10R 세트(~$8)도 좋음.

## 2. 배선 개요 (브레드보드)

```
ESP32-S3 GPIO(PWM) ──> [SN74LVC2G04 버퍼] ──> [40kHz 스피커]   (송신)
                                                  ↓ ))) 스텐실
40kHz 마이크 ──> [OPA344 프리앰프 ~40dB + 밴드패스] ──> ESP32-S3 ADC핀  (수신)
                   └ DC 바이어스 +1.65V (ADC 0~3.3V 중앙)
ESP32-S3 ──USB──> PC (시리얼로 샘플 스트림)
```
- 프리앰프 출력에 **+1.65V DC 바이어스**(저항 분압 + 캐패시터) — ADC가 음수 못 읽으므로 중앙 정렬.
- 스피커와 마이크 사이에 **흡음 배플** — 직접 누설(crosstalk) 차단이 근거리 성능의 핵심.
- 상세 회로·핀맵은 [05_벤치_및_실측H_가이드](05_벤치_및_실측H_가이드.md).

## 3. 한국 구매 메모

- **디바이스마트(devicemart.co.kr) / 엘레파츠(eleparts.co.kr):** OPA344, MCP6002, SN74LVC2G04, 트랜스듀서, 패시브 — 국내 당일~2일.
- **알리익스프레스:** TCT40-16 페어, 트랜스듀서 세트 — 최저가, 배송 1~3주.
- **DigiKey/Mouser 코리아:** Murata 정품 — 정확하나 배송비·관세(15~20%) 가산.
- 직구 가격은 USD 기준, 한국 도착가 = ×환율 + 배송 + 관세.

## 4. 주의 / 폴백

- ⚠️ **ESP32-S3 ADC 연속 100~200kHz 샘플링은 G1에서 반드시 실측 검증.** 기존 `C_SPiDR_재현_구매리스트.md`도 [CRITICAL]로 미검증 표기. 연속 DMA에서 지터·드롭 발생 시:
  - **폴백 1:** 라즈베리파이 **Pico** (~$5, RP2040 ADC 500kHz, 안정적)
  - **폴백 2:** 외장 ADC(ADS 계열) 또는 저가 USB 오실로스코프(~$50)
- ADMP401 **사지 말 것** — 공식 응답 ≤15kHz로 40kHz에서 거의 무응답. 피에조 수신기(MA40S4R)가 40kHz 정합.
- 8Ω 오디오앰프(MAX98357A 등)로 피에조(~2kΩ) 구동 금지 — 임피던스 불일치. 로직버퍼/트랜지스터 사용.

## 5. (선택) 무펌웨어 편의 경로 — ADALM2000

코딩 0·즉시 실험을 최우선하면 [ADALM2000](https://www.digikey.com/en/products/detail/analog-devices-inc/ADALM2000/7019661)(~$287, 신호생성+2ch캡처, libm2k 파이썬). **단 보유 ESP32-S3로 충분하므로 비용상 비추천.**

## 6. 구매 순서

1. **1단계(즉시):** 트랜스듀서 페어(TCT40-16) + OPA344 + 패시브 + 레진 → ~$18. G0(시뮬)은 부품 없이 병행.
2. **2단계(G1 후):** ESP32 ADC가 부족하면 Pico(~$5) 추가.

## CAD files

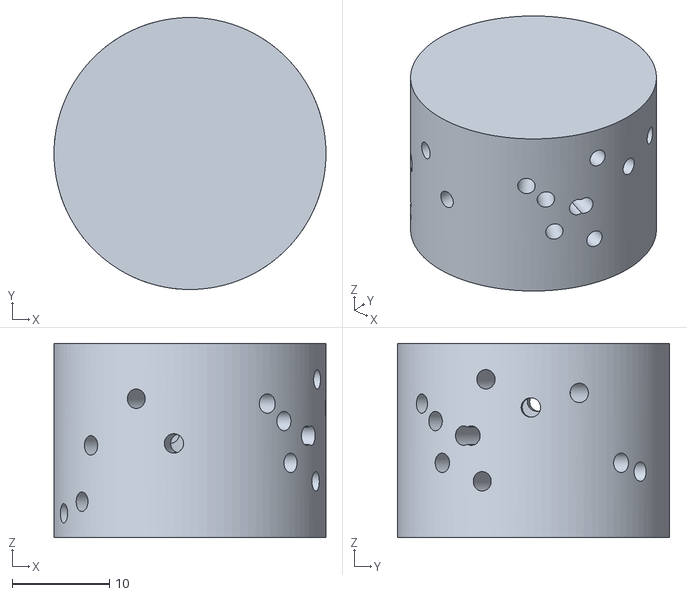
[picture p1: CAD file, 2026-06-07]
models/SPiDR_stencil_parametric.stl
28.0 x 28.0 x 20.0

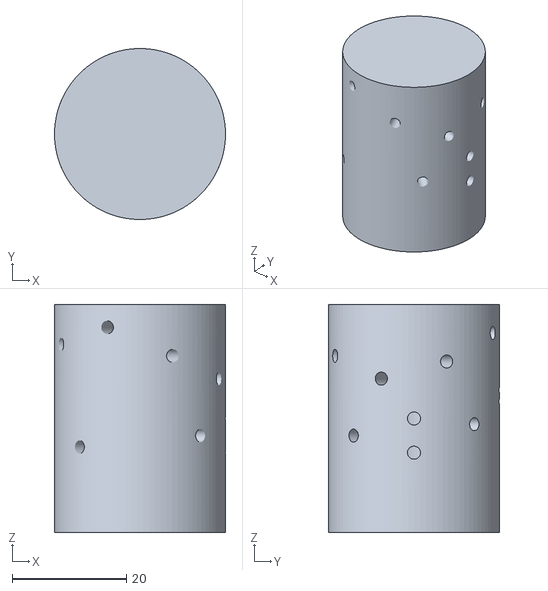
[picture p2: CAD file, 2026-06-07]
models/SPiDR_phasecap_v2.stl
30.0 x 30.0 x 40.0

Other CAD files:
models/SPiDR_phasecap_v2.f3d
models/SPiDR_stencil_parametric.f3d

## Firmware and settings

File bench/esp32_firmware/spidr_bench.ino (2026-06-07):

/*
 * SPiDR 재현 — ESP32-S3 벤치 펌웨어 (spidr_bench.ino)
 * ---------------------------------------------------------------
 * 역할: PC에서 'M' 명령을 받으면, 5개 주파수(38~42kHz) 각각에 대해
 *       10주기 톤버스트를 송출(LEDC PWM)하고, 그 직후 마이크 신호를
 *       ADC 연속(DMA) 모드로 캡처해 시리얼로 스트림한다.
 *       → PC측 daq_io.py 가 이 데이터를 받아 H 측정/복원에 쓴다.
 *
 * 보드: ESP32-S3 (Arduino-ESP32 core 3.x 필요 — analogContinuous API).
 * 배선: TX_PIN → [SN74LVC2G04 버퍼] → 40kHz 스피커
 *       마이크 → [OPA344 프리앰프 + 1.65V 바이어스] → RX_ADC_PIN
 *
 * ⚠️ G1 실측 튜닝 항목(코드 내 TODO):
 *   - SAMPLE_HZ 가 실제로 연속 유지되는지(드롭/지터) 검증. 안 되면 낮추거나 Pico로.
 *   - 버스트-캡처 동기 지연(START_DELAY_US) 보정.
 *   - ADC 채널/감쇠(11dB=0~3.3V) 및 프리앰프 게인으로 클리핑 없이 풀스케일 근접.
 */

#include "Arduino.h"
#include "esp_adc/adc_continuous.h"   // core 3.x

// ---------------- 사용자 설정 ----------------
const int   TX_PIN       = 4;          // 스피커 구동(버퍼 입력)
const int   RX_ADC_CH    = ADC_CHANNEL_3; // GPIO4=CH3 등 보드별 확인. 마이크 입력.
const int   LEDC_CH      = 0;
const float FREQS[]      = {38000, 39000, 40000, 41000, 42000};
const int   N_FREQ       = 5;
const int   BURST_CYCLES = 10;
const int   WIN_SAMPLES  = 240;        // 주파수당 캡처 샘플수(≈1.2ms @200kHz)
const uint32_t SAMPLE_HZ = 200000;     // 목표 샘플레이트 (>80kHz 필수)
const uint32_t START_DELAY_US = 30;    // 버스트 송출~캡처 시작 보정

// ---------------- ADC 연속 핸들 ----------------
adc_continuous_handle_t adc_handle = NULL;
uint8_t adc_buf[1024];

void adc_init() {
  adc_continuous_handle_cfg_t hcfg = { .max_store_buf_size = 2048, .conv_frame_size = 256 };
  adc_continuous_new_handle(&hcfg, &adc_handle);
  adc_digi_pattern_config_t pat = {
    .atten = ADC_ATTEN_DB_12, .channel = RX_ADC_CH, .unit = ADC_UNIT_1, .bit_width = ADC_BITWIDTH_12 };
  adc_continuous_config_t ccfg = {
    .pattern_num = 1, .adc_pattern = &pat,
    .sample_freq_hz = SAMPLE_HZ, .conv_mode = ADC_CONV_SINGLE_UNIT_1,
    .format = ADC_DIGI_OUTPUT_FORMAT_TYPE2 };
  adc_continuous_config(adc_handle, &ccfg);
}

void emit_and_capture(float freq, uint16_t* out, int n) {
  // 1) 톤버스트 송출 (LEDC, 50% 듀티)
  ledcChangeFrequency(LEDC_CH, (uint32_t)freq, 8);
  ledcWrite(LEDC_CH, 128);                       // on
  delayMicroseconds((uint32_t)(1e6 * BURST_CYCLES / freq));
  ledcWrite(LEDC_CH, 0);                          // off
  delayMicroseconds(START_DELAY_US);

  // 2) ADC 연속 캡처
  adc_continuous_start(adc_handle);
  int got = 0; uint32_t rd;
  while (got < n) {
    if (adc_continuous_read(adc_handle, adc_buf, sizeof(adc_buf), &rd, 50) == ESP_OK) {
      for (int i = 0; i < rd && got < n; i += SOC_ADC_DIGI_RESULT_BYTES) {
        adc_digi_output_data_t* p = (adc_digi_output_data_t*)&adc_buf[i];
        out[got++] = p->type2.data;
      }
    }
  }
  adc_continuous_stop(adc_handle);
}

uint16_t window[WIN_SAMPLES];

void setup() {
  Serial.begin(2000000);
  ledcSetup(LEDC_CH, 40000, 8);
  ledcAttachPin(TX_PIN, LEDC_CH);
  ledcWrite(LEDC_CH, 0);
  adc_init();
  Serial.println("# SPiDR bench ready. Send 'M' to measure, 'B' for blank.");
}

void measure(bool blank) {
  Serial.printf("BEGIN %d %d %lu %s\n", N_FREQ, WIN_SAMPLES, SAMPLE_HZ, blank ? "BLANK" : "MEAS");
  for (int f = 0; f < N_FREQ; f++) {
    if (blank) {                    // 빈 장면(배경) — 송출 없이 캡처만? → 동일 송출, 물체 없음
      emit_and_capture(FREQS[f], window, WIN_SAMPLES);
    } else {
      emit_and_capture(FREQS[f], window, WIN_SAMPLES);
    }
    Serial.printf("F %.0f\n", FREQS[f]);
    for (int i = 0; i < WIN_SAMPLES; i++) { Serial.print(window[i]); Serial.print(i==WIN_SAMPLES-1?'\n':','); }
    delay(2);
  }
  Serial.println("END");
}

void loop() {
  if (Serial.available()) {
    char cmd = Serial.read();
    if (cmd == 'M') measure(false);
    else if (cmd == 'B') measure(true);  // 배경(물체 제거 상태에서 호출)
  }
}

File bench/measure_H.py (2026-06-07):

"""
SPiDR 재현 — 실측 채널행렬 H 측정 (measure_H.py)  ★이 재현의 심장★

프로토콜:
1. 물체를 모두 치우고 배경(blank) 측정 → 직접누설·고정에코 기록.
2. 작은 점반사체(예: Ø6mm 금속구/막대)를 픽셀 격자의 각 위치로 옮기며 측정.
3. 각 측정에서 배경을 빼고(클러터 제거) 동기 평균(SNR↑) → H의 그 열.
4. 모든 픽셀 완료 → H_measured.npz 저장. 이후 reconstruct로 실제 장면 복원.

처음엔 1D(가로 한 줄)로, 손+자+3D프린트 지그로 충분(모터 불필요).
실행: python measure_H.py --port COM5      (하드웨어)
      python measure_H.py --sim            (하드웨어 없이 파이프라인 점검)
"""
from __future__ import annotations
import argparse, sys, numpy as np
sys.path.insert(0, '../sim')
from forward_model import Config, make_stencil, scene_grid
import daq_io


def grid_1d(pitch_cm=2, depth_cm=10):
    x_cm = np.arange(-10, 10 + 1e-9, pitch_cm)
    pix, _ = scene_grid(x_cm, [depth_cm])
    return pix, x_cm


def measure_real(port, pix, x_cm, depth_cm, n_avg=32):
    ser = daq_io.open_port(port)
    input("물체를 모두 치우고 Enter (배경 측정)...")
    blank = daq_io.capture_avg(ser, n_avg, blank=False)   # 배경(빈 장면)
    cols = []
    for i, xc in enumerate(x_cm):
        input(f"[{i+1}/{len(x_cm)}] 점반사체를 (x={xc:+.0f}cm, depth={depth_cm}cm)에 놓고 Enter...")
        meas = daq_io.capture_avg(ser, n_avg)
        col = daq_io.to_column(meas - blank)              # ★배경차감★
        cols.append(col)
    H = np.stack(cols, axis=1)
    return H


def measure_sim(pix, x_cm):
    cfg = Config(); rng = np.random.default_rng(0)
    src, L = make_stencil(cfg)
    cols = [daq_io.capture_sim(i, pix, src, L, cfg, rng) for i in range(len(pix))]
    return np.stack(cols, axis=1)


if __name__ == "__main__":
    ap = argparse.ArgumentParser()
    ap.add_argument("--port"); ap.add_argument("--sim", action="store_true")
    ap.add_argument("--pitch", type=float, default=2); ap.add_argument("--depth", type=float, default=10)
    ap.add_argument("--navg", type=int, default=32)
    a = ap.parse_args()
    pix, x_cm = grid_1d(a.pitch, a.depth)
    if a.sim:
        H = measure_sim(pix, x_cm)
        print(f"[SIM] H_measured shape={H.shape}")
    else:
        if not a.port: sys.exit("--port COMx 필요 (또는 --sim)")
        H = measure_real(a.port, pix, x_cm, a.depth, a.navg)
    np.savez("H_measured.npz", H=H, x_cm=x_cm, depth_cm=a.depth, pitch=a.pitch)
    # 품질 지표
    Hn = H / (np.linalg.norm(H, axis=0, keepdims=True) + 1e-12)
    G = np.abs(Hn.T @ Hn); np.fill_diagonal(G, 0)
    print(f"저장 H_measured.npz | 최대 열결맞음={G.max():.3f} 조건수={np.linalg.cond(H):.1f}")
    print("→ 이제 reconstruct로 실제 장면(여러 물체) 복원 가능 (06 가이드 G3).")
